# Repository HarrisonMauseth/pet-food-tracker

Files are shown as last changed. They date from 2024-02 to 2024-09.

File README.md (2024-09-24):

# Pet Food Tracker Overview
This project stems from living in a house with four dogs who love to lie about how much food they have eaten. Since the dogs often slept in different rooms, there was not really a great system to ensure they all got fed the proper amount.

The solution? Create a display that lives near the dog food with physical buttons and a UI simple enough that a 5 year old can operate it while leaving myself room to iterate on the design as I learn more.

In order to accomplish this, I needed to do the following:

- Gather hardware for the physical controller and console
- Write code to control the hardware
- Create a simple printed circuit board to reduce wiring clutter
- Design a container in Fusion 360 to house the hardware
- 3D Print the container, solder the parts, and rollout the device to my home

## Key Directories
While the project is by no means massive, it is worth highlighting a few of the key directories found in this repository:

- `arduino-code` - contains the `main.cpp` file where the code for the standalone device lives
- `pcb-files` - as the name suggests, this directory is where you can find the files associated with the printed circuit board
- `stl-files` - if you are looking to find the files for 3D printing, they stored here
- `server` - where the Spring Boot Java server and RESTful API is stored 

## Roadmap
I am tackling this project with a three phased approach:
- [Phase One](#phase-one-completed---standalone-device) - initial design and implementation of standalone device **(Completed)**
- [Phase Two](#phase-two-completed---database-design-and-server-side-api) - design a database and server to be accessible via a RESTful API **(Completed)**
- [Phase Three](#phase-three---client-side-web-app) - client side web appication using a SPA framework such as Vue.js **(In Prorgress)**
- [Phase Four](#phase-four---arduino-project-rework) - repurpose the standalone arduino porject to leverage the server-side API

At this time, phase one is complete and the standalone device mentioned previously works as intended. I am currently working on creating a REST API written in Java that leverages Spring Boot.

## Phase One (Completed) - Standalone Device
This is where the project started. All I wanted was a physical device to sit on my counter to reduce the excessive daily conversations about whether or not the dogs have been fed. This phase of the project accomplished exactly that. 

### Hardware Required
The following hardware was used on the physical device. Since the 3D printed container was modeled based on these specific brands, I have included a link to the exact models I purchased. With that said, there is no way for me to be certain that the products stayed consistent since my purchase in July of 2023, so your milage may vary:

- ESP32 Microcontroller [(Sold by Flutesan on Amazon)](https://www.amazon.com/dp/B09GK74F7N)
- LCD2004 I2C Serial LCD [(Sold by GeekPi on Amazon)](https://www.amazon.com/dp/B09GK74F7N/)
- HC-SR501 PIR sensor [(Sold by DIYmall on Amazon)](https://www.amazon.com/gp/product/B012ZZ4LPM)
- 4-Pin Tactile Push Button Momentary Switch [(Sold by TWTADE on Amazon)](https://www.amazon.com/gp/product/B07CG7VTGD)
- M3 x 5.7mm Threaded Inserts [(Sold by Ruthex on Amazon)](https://www.amazon.com/gp/product/B08BCRZZS3)

In addition to this, I also designed a printed circuit board (PCB) for stability and cleanliness. Should you want to order your own, I have included the KiCad files and the gerber files needed for ordering from a site like PCBWay in the `pcb-files` directory of this repository.

The PCB is quite simplistic. It provides a flush mount for 6 momentary switches and the ESP32.  It also provides solder pads for the 20x4 LCD wiring as well as the IR sensor wiring.

The LCD can print up to 4 rows, 20 characters each. On the back, it has a jumper cable that connects the positive terminal to the backlight. I removed this jumper cable and instead wired up a PIR sensor so that way I can have the display turn on automatically as I approach the device.

### Code for Physical Implementation
In the current state of the project, the code for the physical device does the following:
- Assigns the GPIO of the the ESP32
- Provides a series of variables that track elapsed time
- Prints information to the LCD screen
- Provides logic to control the LCD backlight via IR sensor
- Provides logic to print correct time frames

The code for this project was written before I ever had any formal training on industry standards. While I see plenty of opportunities to refactor this code, it functions exactly as I intended it to and is still fairly concise given the lack of coding knowledge I had at the time of writing this. With that said, there were quite a few challenges I needed to overcome.

The first hurdle was implementing the logic to track elapsed time without using timestamps in a database. I ended up using Arduino's `millis()` function which returns the number of milliseconds passed since the current program began running. Given that the datatype is an unsigned long, there is the inevitability that this will reset after about 50 days. While far from perfect, human error (read: we forget to push the buttons) happens about once or twice per week. This ended up being an acceptable compromise for the scope of the project. 

The second challenge was figuring out the best way to print the elapsed times to the LCD. I wanted something that looks nice, clean, and can convey all of the information with the strict limit of 20 characters per line. I opted for doing having a "right aligned column" for the dog names and then a left aligned column for the timers. Additionally, instead of displaying a continuous stopwatch, I opted for phrases like "now eating", "5 hours ago", and "safe to eat". This was less of a challenge of logic and more of a challenge of design, but we landed somewhere that works perfectly for our house.

The last challenge was refactoring my code. With zero coding experience, this was by far the hardest part of the project for me at the time. As is the theme of this project, it is far from perfect. As they say, hindsight is 20/20. And while I see plenty of opportunity to refactor and implement the principles of Object Oriented Programming, I'm just happy that I had the foresight to break this down into bite-sized methods with meaningful variable names. Since the plan is to overhaul the code to be a client-side API, I don't see any point in cleaning this up to show off my skills now. To me, the code holds more value as a memento of who I was when I started coding and can help me get out of a mental block when the imposter syndrome inevitably comes up.

### Printed Circuit Board (PBC) Layout
The PCB for this project is rudimentary. There are no complex timing chips or resistors needed. The goal was to provide a sturdy mounting plate for the ESP32 and the 6 buttons. The added benefit is that it reduces the clutter from wires and helps eliminate confusion during the soldering process. Given that this was designed for a specific ESP32 and some specific momentary switches, your milage may vary.

The KiCad project files and the Gerber files can be found within the `pcb-files` directory of the repository.

### 3D Printing Design
As is the case with the PCB, I have designed the case to fit the specific hardware. As much as I loved having the breadboard and exposed wires out, I knew that a long-term solution was needed. I opted for a design that has a bit of a retro feel. The design choice was simply based on making the 3D printing process easier. 

All files can be printed without supports. I printed this in a black PLA filament. The base holds the PCB and has cutouts to feed the wires. There is a cover that sits flush with the specific model of momentary switches. The top of the case holds the LCD and the infrared sensor. I have also included some guide holes to allow for threaded inserts. See the hardware list for more information.

## Phase Two (Completed) - Database Design and Server-Side API
This phase is effectively everything server-side. This can be broken down intot he following features:

- Created a PostgreSQL database to track timestamps, serving sizes, nutritious facts, etc.
- Developed a Java application for accessing the data using Spring's JDBC
- Implemented a server-side RESTful API using Spring Boot
- Included authentication for multiple users using Spring Security and JWTs

## Phase Three - Client-Side Web App
This is the current phase of the project. The plan is to develop a web application using a SPA framework (Vue.js) to allow for remote access to the database.

### User Stories
In this section, we will define two types of users:
- Anonymous user: a user who has not yet logged in to the application
- Authenticated user: a user who has registered an account and is logged in to the application

#### Registration and Login
- As an anonymous user, I am greeted with a login page
    - Upon logging in, I am redirected to the pet dashboard (home page)
- As an anonymous user, I can register a new account
    - Clicking the "register accoount" button takes me to the register view
- As an authenticated user, I can click "Logout" to log out of the application
    - After logging out, the system redirects me to the login page

#### Dashboard
The home dashboard can only be seen by an authenticated user. Assume that each of the stories listed below begins with "as an authenticated user".

- I can acces this page using the route `/home`
- I am presented with all of my pets (if any)
    - If I have no pets, I am simply given the option to add a pet
    - If I do have pets, the first option should be "feed all"
    - Each pet should have the option to feed only that pet
- I can click the button to create a new pet
    - Clicking on "add pet" will redirect to the pet creation view
- Each pet should have a dynamic timer showing how long it has been since they have been fed
    - For example, a display like "now eating" or "last fed 35 minutes ago" should exist. 
    - If a pet has not been fed within 10-12 hours, the style of the card should change to reflect this
    - If a pet has not been fed within 12 hours, the style of the card should change to reflect the urgency

#### Pet Details Page
The pet details page can only be seen by an authenticated user. Assume that each of the stories listed below begins with "as an authenticated user".

- I can access this page using the route `/pets/{id}` where `id` is the pet id (for example, `pets/1`)
- I can see a full list of details about the pet
    - Any detail that is null in the database should not be rendered
- I have the option to remove the pet
    - Clicking the remove pet button requires a secondary confirmation
    - A message should dispaly to me that verifies that this operation was completed/failed

#### Add Pet Page
The add pet page can only be seen by an authenticated user. Assume that each of the stories listed below begins with "as an authenticated user".

- I can access this page using the route `/pets/add`
- Any field that is required is clearly denoted
- Upon creating, a message should dispaly to me that verifies that this operation was completed/failed

#### Log Overview Page
The log overview page can only be seen by an authenticated user. Assume that each of the stories listed below begins with "as an authenticated user".

- I can access this page using the route `/logs`
- I can view all logs for all pets
- Each log should show a brief overview (edit, pet name, time fed, remove)
- I can click on a specific log to see the details of the log
- Each log should have the option to remove
    - Clicking the remove pet button requires a secondary confirmation
    - A message should dispaly to me that verifies that this operation was completed/failed
- Each log should have the option to edit
    - Clicking the edit button should display a modal with the edit form

#### Log Details Page
The log details page can only be seen by an authenticated user. Assume that each of the stories listed below begins with "as an authenticated user".

- I can acces this page using the route `/logs/{id}` where the `id` is the log id (for example, `logs/1`)

## Phase Four - Arduino Project Rework
Once the server and client are up and running, the plan is to rewrite the code for the physical device so it acts as a physical client. This will allow for anyone in the house to utilize the web application or the physical component without fear of data loss due to power-outages.

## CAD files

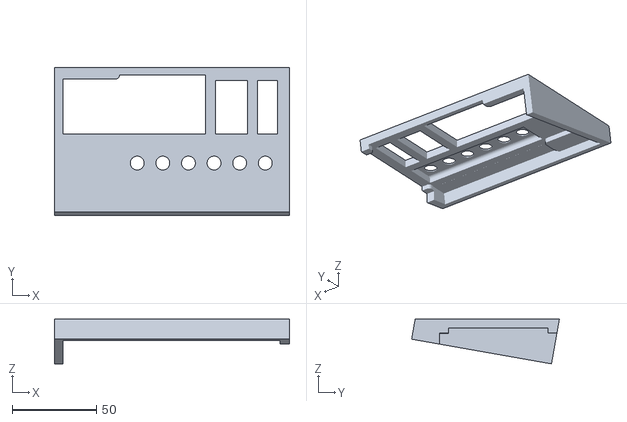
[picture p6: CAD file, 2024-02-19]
standalone-device/stl-files/TimerButtonCover-v2.0.stl
139.8 x 87.9 x 26.6

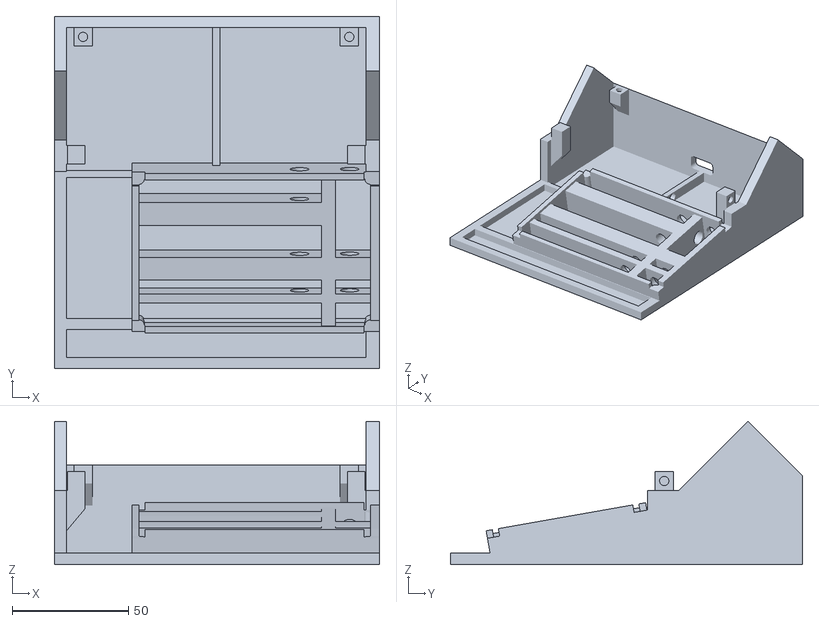
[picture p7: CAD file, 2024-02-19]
standalone-device/stl-files/TimerBase-v2.0.stl
139.8 x 151.5 x 61.7

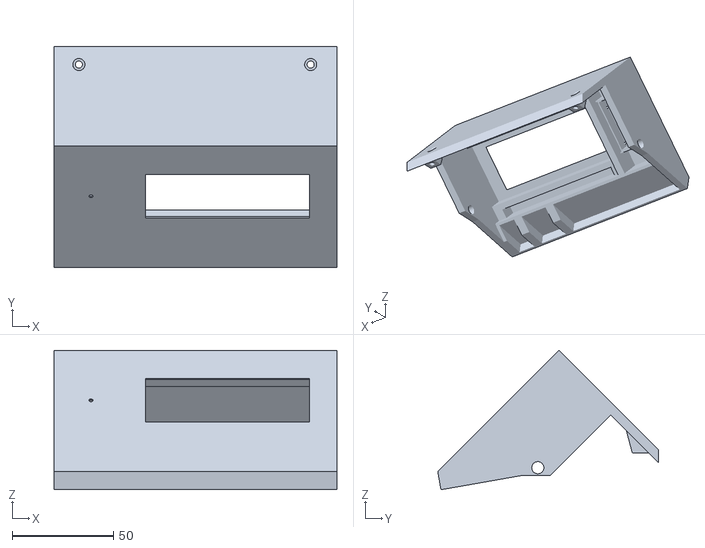
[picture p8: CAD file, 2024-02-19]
standalone-device/stl-files/TimerLCD-v2.0.stl
139.8 x 109.0 x 68.9

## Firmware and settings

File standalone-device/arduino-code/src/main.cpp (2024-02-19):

#include <Arduino.h>
#include <Wire.h>
#include <hd44780.h>
#include <hd44780ioClass/hd44780_I2Cexp.h>

// initialize LED
hd44780_I2Cexp lcd;
const int LCD_COLUMN_CHARACTER_COUNT = 20;
const int LCD_ROW_CHARACTER_COUNT = 4;

// GPIO layout
const int PIN_BUTTON_1   =  4;
const int PIN_BUTTON_2   = 18;
const int PIN_BUTTON_3   = 19;
const int PIN_BUTTON_4   = 14;
const int PIN_BUTTON_5   = 27;
const int PIN_BUTTON_6   = 26;
const int PIN_BACKLIGHT  = 23;
const int PIN_PIR_SENSOR = 33;

// Button and Sensor Names
unsigned int button1 = 0;
unsigned int button2 = 0;
unsigned int button3 = 0;
unsigned int button4 = 0;
unsigned int button5 = 0;
unsigned int button6 = 0;
unsigned int motionSensor = 0;

// Dog names for screen
String dogB = "  Bucky: ";
String dogE = "  Ender: ";
String dogP = "Pretzel: ";
String dogS = " Stormy: ";

// Timestamps
unsigned long stampB1 = 0;
unsigned long stampB2 = 0;
unsigned long stampB3 = 0;
unsigned long stampB4 = 0;
unsigned long stampB5 = 0;
unsigned long stampB6 = 0;
unsigned long stampBL = 0;

// Elapsed Timers
unsigned long currentTime = 0;
unsigned long timeSinceB1 = 0;
unsigned long timeSinceB2 = 0;
unsigned long timeSinceB3 = 0;
unsigned long timeSinceB4 = 0;
unsigned long timeSinceB5 = 0;
unsigned long timeSinceB6 = 0;
unsigned long timeSinceBL = 0;

// Define timekeeping constants
const unsigned long HOURS_IN_MILLIS   = 3600000;
const unsigned long MINUTES_IN_MILLIS = 60000;
const unsigned long SECONDS_IN_MILLIS = 1000;

// LCD Refreshrate
unsigned long previousTime   = 0;
const unsigned int REFRESH_RATE_IN_MILLIS = 200;
const unsigned int BACKLIGHT_TIMEOUT      = 15 * SECONDS_IN_MILLIS;

// Print Bucky's Name
void bucky() {
  lcd.setCursor(0,0);
  lcd.print(dogB);
}

// Print Ender's Name
void ender() {
  lcd.setCursor(0,1);
  lcd.print(dogE);
}

// Print Pretzel's Name
void pretzel() {
  lcd.setCursor(0,2);
  lcd.print(dogP);
}

// Print Stormy's Name
void stormy() {
  lcd.setCursor(0,3);
  lcd.print(dogS);
}

// Array to call when you need to display times
String timeSinceFed[] = {
  "Now eating!", //  0
  "Recently   ", //  1
  "1 hour ago ", //  2
  "2 hours ago", //  3
  "3 hours ago", //  4
  "4 hours ago", //  5
  "5 hours ago", //  6
  "6 hours ago", //  7
  "7 hours ago", //  8
  "8 hours ago", //  9
  "9 hours ago", // 10
  "Safe to Eat", // 11
  "NEEDS FOOD!", // 12
  "updating..."  // 13
} ;

// Print times based off timeSinceFed array
void printElapsedTime(unsigned long myTime) {
  if (myTime < .2 * SECONDS_IN_MILLIS) {
    lcd.print(timeSinceFed[13]);
  } else if (myTime < 5 * MINUTES_IN_MILLIS) {
    lcd.print(timeSinceFed[0]);
  } else if (myTime < 1 * HOURS_IN_MILLIS) {
    lcd.print(timeSinceFed[1]);
  } else if (myTime < 2 * HOURS_IN_MILLIS) {
    lcd.print(timeSinceFed[2]);
  } else if (myTime < 3 * HOURS_IN_MILLIS) {
    lcd.print(timeSinceFed[3]);
  } else if (myTime < 4 * HOURS_IN_MILLIS) {
    lcd.print(timeSinceFed[4]);
  } else if (myTime < 5 * HOURS_IN_MILLIS) {
    lcd.print(timeSinceFed[5]);
  } else if (myTime < 6 * HOURS_IN_MILLIS) {
    lcd.print(timeSinceFed[6]);
  } else if (myTime < 7 * HOURS_IN_MILLIS) {
    lcd.print(timeSinceFed[7]);
  } else if (myTime < 8 * HOURS_IN_MILLIS) {
    lcd.print(timeSinceFed[8]);
  } else if (myTime < 9 * HOURS_IN_MILLIS) {
    lcd.print(timeSinceFed[9]);
  } else if (myTime < 10 * HOURS_IN_MILLIS) {
    lcd.print(timeSinceFed[10]);
  } else if (myTime < 12 * HOURS_IN_MILLIS){
    lcd.print(timeSinceFed[11]);
  } else {
    lcd.print(timeSinceFed[12]);
  }
}

// Turn the backlight on
void enableBacklight() {
  digitalWrite(PIN_BACKLIGHT, HIGH);
}

// Turn the backlight off
void disableBacklight() {
  digitalWrite(PIN_BACKLIGHT, LOW);
}

// Reset the backlight timer
void resetBacklightTimer() {
  stampBL = currentTime;
}

// Logic for button 1
void pushButton1() {
  if (button1 == LOW) {
    stampB1 = currentTime;
    resetBacklightTimer();    
  }
}

// Logic for button 2
void pushButton2() {
  if (button2 == LOW) {
    stampB2 = currentTime;
    resetBacklightTimer();
  }  
}

// Logic for button 3
void pushButton3() {
  if (button3 == LOW) {
    stampB3 = currentTime;
    resetBacklightTimer();
  }
}

// Logic for button 4
void pushButton4() {
  if (button4 == LOW) {
    stampB4 = currentTime;
    resetBacklightTimer();
  }  
}

// Logic for button 5
void pushButton5() {
  if (button5 == LOW) {
    stampB1 = currentTime;
    stampB2 = currentTime;
    stampB3 = currentTime;
    stampB4 = currentTime;
    stampB5 = currentTime;
    resetBacklightTimer();
  }
}

// Logic for button 6
void pushButton6() {
  if (button6 == LOW) {
    stampB6 = currentTime;
    resetBacklightTimer();
  }  
}

// Logic for backlight
void checkBacklight() {
  if (motionSensor == HIGH) {
    enableBacklight();
    resetBacklightTimer();
  } else if (timeSinceBL <= BACKLIGHT_TIMEOUT) {
    enableBacklight();
  } else {
    disableBacklight();
  }
}

// Reads GPIO and checks for button presses
void checkButtonUpdates() {
  button1 = digitalRead(PIN_BUTTON_1);
  button2 = digitalRead(PIN_BUTTON_2);
  button3 = digitalRead(PIN_BUTTON_3);
  button4 = digitalRead(PIN_BUTTON_4);
  button5 = digitalRead(PIN_BUTTON_5);
  button6 = digitalRead(PIN_BUTTON_6);
  motionSensor = digitalRead(PIN_PIR_SENSOR);
  pushButton1();
  pushButton2();
  pushButton3();
  pushButton4();
  pushButton5();
  pushButton6();
}

// Updates the timers
void updateTimers() {
  currentTime = millis();
  timeSinceB1 = currentTime - stampB1;
  timeSinceB2 = currentTime - stampB2;
  timeSinceB3 = currentTime - stampB3;
  timeSinceB4 = currentTime - stampB4;
  timeSinceB5 = currentTime - stampB5;
  timeSinceB6 = currentTime - stampB6;
  timeSinceBL = currentTime - stampBL;
}

// Print updated info to the LCD
void screenRefresh () {
  if (currentTime - previousTime >= REFRESH_RATE_IN_MILLIS) {
  bucky();
  printElapsedTime(timeSinceB1);
  ender();
  printElapsedTime(timeSinceB2);
  pretzel();
  printElapsedTime(timeSinceB3);
  stormy();
  printElapsedTime(timeSinceB4);
  previousTime = currentTime;
  }
}

// Bootup sequence
void setup() {
  Serial.begin(115200);

  // Initialize GPIO types using the internal pull up resistor instead of hard wiring one
  pinMode (PIN_BUTTON_1, INPUT_PULLUP); 
  pinMode (PIN_BUTTON_2, INPUT_PULLUP);
  pinMode (PIN_BUTTON_3, INPUT_PULLUP);
  pinMode (PIN_BUTTON_4, INPUT_PULLUP);
  pinMode (PIN_BUTTON_5, INPUT_PULLUP);
  pinMode (PIN_BUTTON_6, INPUT_PULLUP);
  pinMode (PIN_BACKLIGHT, OUTPUT);
  pinMode (PIN_PIR_SENSOR, INPUT);

  // Initiialize LCD Screen settings
  int status;  
  status = lcd.begin(LCD_COLUMN_CHARACTER_COUNT,LCD_ROW_CHARACTER_COUNT);
  if (status) {
    hd44780::fatalError(status);
  }
  lcd.noBlink();
  lcd.noAutoscroll();
  enableBacklight();
}

// Main sequence
void loop() {
  updateTimers();
  checkBacklight();
  checkButtonUpdates();
  screenRefresh();
}

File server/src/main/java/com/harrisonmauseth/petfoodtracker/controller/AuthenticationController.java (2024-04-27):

package com.harrisonmauseth.petfoodtracker.controller;

import com.harrisonmauseth.petfoodtracker.dao.UserDao;
import com.harrisonmauseth.petfoodtracker.dto.LoginDto;
import com.harrisonmauseth.petfoodtracker.dto.LoginResponseDto;
import com.harrisonmauseth.petfoodtracker.dto.RegisterUserDto;
import com.harrisonmauseth.petfoodtracker.exception.DaoException;
import com.harrisonmauseth.petfoodtracker.model.UserEntity;
import com.harrisonmauseth.petfoodtracker.security.JwtTokenProvider;
import org.springframework.beans.factory.annotation.Autowired;
import org.springframework.http.HttpStatus;
import org.springframework.http.ResponseEntity;
import org.springframework.security.access.prepost.PreAuthorize;
import org.springframework.security.authentication.AuthenticationManager;
import org.springframework.security.authentication.UsernamePasswordAuthenticationToken;
import org.springframework.security.core.Authentication;
import org.springframework.security.core.context.SecurityContextHolder;
import org.springframework.security.crypto.password.PasswordEncoder;
import org.springframework.web.bind.annotation.CrossOrigin;
import org.springframework.web.bind.annotation.PostMapping;
import org.springframework.web.bind.annotation.RequestBody;
import org.springframework.web.bind.annotation.RestController;
import org.springframework.web.server.ResponseStatusException;

/**
 * AuthenticationController is a class used for handling requests to authenticate Users.
 * <p>
 * It depends on an instance of a UserDao for retrieving and storing user data and is
 * provided through dependency injection.
 */
@RestController
@CrossOrigin
public class AuthenticationController {

    private AuthenticationManager authenticationManager;
    private UserDao userDao;
    private PasswordEncoder passwordEncoder;
    private JwtTokenProvider jwtTokenProvider;

    @Autowired
    public AuthenticationController(AuthenticationManager authenticationManager,
                                    UserDao userDao,
                                    PasswordEncoder passwordEncoder,
                                    JwtTokenProvider jwtTokenProvider) {
        this.authenticationManager = authenticationManager;
        this.userDao = userDao;
        this.passwordEncoder = passwordEncoder;
        this.jwtTokenProvider = jwtTokenProvider;
    }

    @PostMapping("/login")
    public LoginResponseDto login(@RequestBody LoginDto loginDto) {
        try {
            Authentication authentication = authenticationManager.authenticate(
                    new UsernamePasswordAuthenticationToken(loginDto.getUsername(), loginDto.getPassword()));
            SecurityContextHolder.getContext().setAuthentication(authentication);
            String jwt = jwtTokenProvider.createToken(authentication, loginDto.isRemembered());

            UserEntity user = userDao.getUserByUsername(loginDto.getUsername());
            return new LoginResponseDto(jwt, user);
        } catch (DaoException e) {
            throw new ResponseStatusException(HttpStatus.INTERNAL_SERVER_ERROR, "DAO error - " + e.getMessage());
        }

    }

    @PostMapping("/register")
    @PreAuthorize("permitAll")
    public ResponseEntity<String> register(@RequestBody RegisterUserDto registerUserDto) {
        if (userDao.existsByUsername(registerUserDto.getUsername())) {
            return new ResponseEntity<>("Username is taken", HttpStatus.BAD_REQUEST);
        }
        UserEntity user = new UserEntity();
        user.setUsername(registerUserDto.getUsername());
        user.setPassword(passwordEncoder.encode(registerUserDto.getPassword()));
        user.setRoles("USER");
        user.setActivated(true);

        try {
            userDao.createUser(user);
        } catch (DaoException e) {
            return new ResponseEntity<>("Unable to connect to database", HttpStatus.INTERNAL_SERVER_ERROR);
        }
        return new ResponseEntity<>("User registered successfully", HttpStatus.CREATED);
    }


}

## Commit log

2024-02-19 initial commit - see readme for project overveiw
    [DogFoodReminderPCB-B_Cu.gbl, DogFoodReminderPCB-B_Mask.gbs, DogFoodReminderPCB-B_Silkscreen.gbo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]
2024-04-27 reorganization of project folder structure to clarify server-side, arduino, and misc files
2024-05-04 deletePetByPetId now ensures authenticated user is the one deleting, integration testing reflects current state of dao
2024-05-21 moved all directories related to phase one into the standalone-device directory
    [DogFoodReminderPCB-B_Cu.gbl, DogFoodReminderPCB-B_Mask.gbs, DogFoodReminderPCB-B_Silkscreen.gbo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]
2024-06-03 extracted the feed button from PetCard into a FeedButton component
